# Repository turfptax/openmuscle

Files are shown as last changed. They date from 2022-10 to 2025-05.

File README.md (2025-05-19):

# 🧠 OpenMuscle (Legacy Repository)

> 📢 **NOTE:** This repository is no longer actively maintained.  
> All current work has moved to the new [**Open-Muscle GitHub Organization**](https://github.com/Open-Muscle).  
> Please see the new [OpenMuscle Hub](https://github.com/Open-Muscle/OpenMuscle-Hub) for the latest devices, firmware, and documentation.

---

## ⚡ Quick Links to New Repositories

| Project | Description | Link |
|---|---|---|
| **OpenMuscle Hub** | Central documentation and overview for all OpenMuscle projects | [OpenMuscle-Hub](https://github.com/Open-Muscle/OpenMuscle-Hub) |
| **FlexGrid** | Modular 60-sensor wearable (successor to OM12) | [OpenMuscle-FlexGrid](https://github.com/Open-Muscle/OpenMuscle-FlexGrid) |
| **LASK5** | Labeling device with joystick and buttons | [OpenMuscle-LASK5](https://github.com/Open-Muscle/OpenMuscle-LASK5) |
| **Software** | MicroPython firmware, communication protocols, and ML hooks | [OpenMuscle-Software](https://github.com/Open-Muscle/OpenMuscle-Software) |
| **OM12 Legacy Band** | Historical 12-sensor band hardware | [OpenMuscle-Band](https://github.com/Open-Muscle/OpenMuscle-Band) |

---

## 🧬 About This Repo

This was the **original prototype** of OpenMuscle (OM12 + LASK4), developed to prove out muscle-based finger tracking using off-the-shelf parts and MicroPython.

It remains here for archival purposes and for those referencing:
- Early research and design iterations
- Press and academic mentions (42+ stars)
- Explorations in UDP-based muscle telemetry using hall effect sensors

<div align="center">
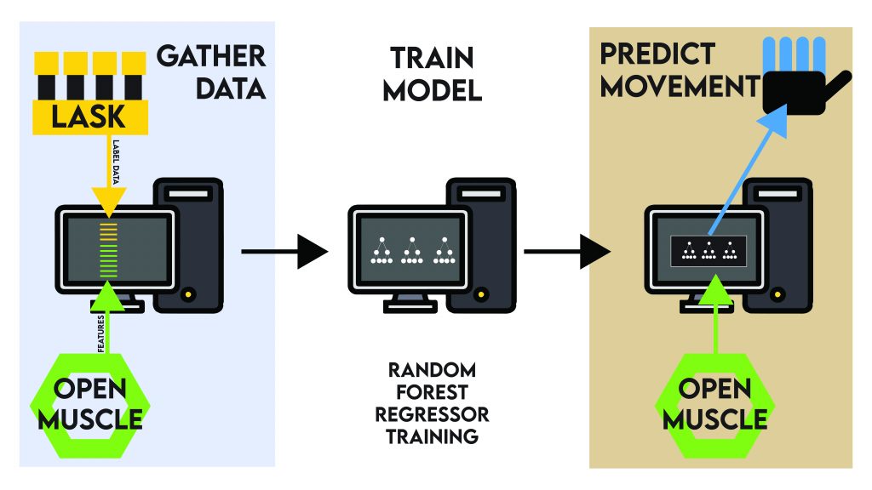
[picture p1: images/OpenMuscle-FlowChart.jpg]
OpenMuscle Flow Chart
    
</div>

---

## 🧪 Prototype Overview

### 🧠 OM12 – OpenMuscle 12 Sensor Band (v5.3.0)

- 12 Hall Effect Sensors (49E)
- 6 Sensor Cells, dual-input
- PCB 5.3.0
- ESP32-S2
- MicroPython
- 1200 s/s via UDP transmission

### ✋ LASK4 (Legacy)

- 4 pistons
- 4 push buttons
- OLED screen
- ESP32-S2 Microcontroller

> The latest version is [LASK5](https://github.com/Open-Muscle/OpenMuscle-LASK5), with joystick and modular controls.

---

## ✅ Legacy Roadmap (Preserved for Context)

- [x] Create an open-source forearm bracelet (OM12)
- [x] Build a hand gesture labeling device (LASK4)
- [x] Create UDP-based data capture tool
- [ ] Build a hosted data training server
- [ ] Raise community awareness
- [ ] Create pre-production versions of both devices

---

## 🧾 License

This repo remains under the MIT License, but newer repositories may use the CERN-OHL-S v2.0 for hardware components. See the respective repos for details.

---

Made with 💡 by [@TURFPTAx](https://github.com/turfptax)  
Project now maintained at [Open-Muscle](https://github.com/Open-Muscle)

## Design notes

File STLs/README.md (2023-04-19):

# STL Files for Open Muscle

## OM12 Foam

Most recent design that reduces cost and time of manufactoring

## OM12 Clevis Pin

Best signal-to-noise ratio design. Used for datasetONE and January23.csv

#### Clevis Pin Sensors
<br />
<div align="center">
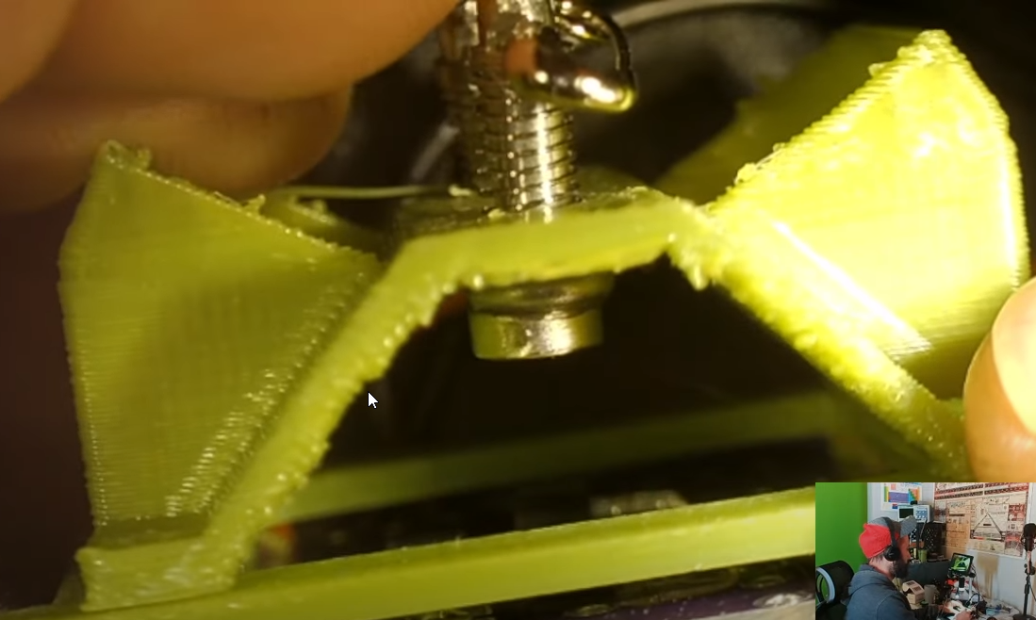
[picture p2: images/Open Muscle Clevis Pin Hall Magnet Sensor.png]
    
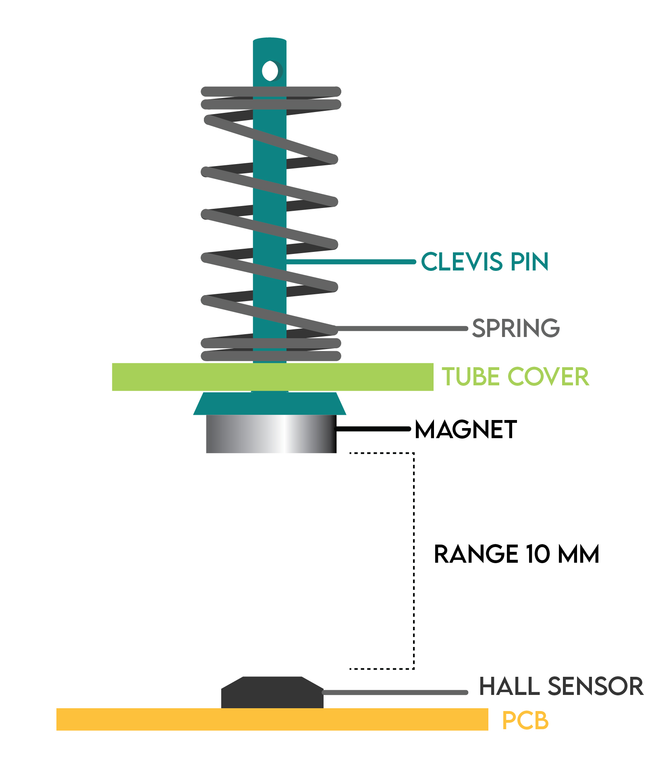
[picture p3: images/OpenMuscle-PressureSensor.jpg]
    
</div>

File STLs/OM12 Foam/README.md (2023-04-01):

# STL Files for Open Muscle

## OM12-BeltHolder
Main PCB bracer and has loops for the elastic band

## OM12-FoamHolder
Sensor side piece that holds the foam/magnet sensors

## OM12-Magnet Tool 6x3
Tool to help glue the magnets onto the rubber sheet.

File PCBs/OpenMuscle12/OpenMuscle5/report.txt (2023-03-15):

Plotted to 'C:\Users\ToryMoghadam\TMO-GMO-FILES\CELL0\OpenMuscle5\OpenMuscle5\OM5-Gerber\OpenMuscle5-F_Cu.gbr'.
Plotted to 'C:\Users\ToryMoghadam\TMO-GMO-FILES\CELL0\OpenMuscle5\OpenMuscle5\OM5-Gerber\OpenMuscle5-B_Cu.gbr'.
Plotted to 'C:\Users\ToryMoghadam\TMO-GMO-FILES\CELL0\OpenMuscle5\OpenMuscle5\OM5-Gerber\OpenMuscle5-F_Paste.gbr'.
Plotted to 'C:\Users\ToryMoghadam\TMO-GMO-FILES\CELL0\OpenMuscle5\OpenMuscle5\OM5-Gerber\OpenMuscle5-B_Paste.gbr'.
Plotted to 'C:\Users\ToryMoghadam\TMO-GMO-FILES\CELL0\OpenMuscle5\OpenMuscle5\OM5-Gerber\OpenMuscle5-F_Silkscreen.gbr'.
Plotted to 'C:\Users\ToryMoghadam\TMO-GMO-FILES\CELL0\OpenMuscle5\OpenMuscle5\OM5-Gerber\OpenMuscle5-B_Silkscreen.gbr'.
Plotted to 'C:\Users\ToryMoghadam\TMO-GMO-FILES\CELL0\OpenMuscle5\OpenMuscle5\OM5-Gerber\OpenMuscle5-F_Mask.gbr'.
Plotted to 'C:\Users\ToryMoghadam\TMO-GMO-FILES\CELL0\OpenMuscle5\OpenMuscle5\OM5-Gerber\OpenMuscle5-B_Mask.gbr'.
Plotted to 'C:\Users\ToryMoghadam\TMO-GMO-FILES\CELL0\OpenMuscle5\OpenMuscle5\OM5-Gerber\OpenMuscle5-Edge_Cuts.gbr'.
Created Gerber job file 'C:\Users\ToryMoghadam\TMO-GMO-FILES\CELL0\OpenMuscle5\OpenMuscle5\OM5-Gerber\OpenMuscle5-job.gbrjob'.
Plotted to 'C:\Users\ToryMoghadam\TMO-GMO-FILES\CELL0\OpenMuscle5\OpenMuscle5\OM5-Gerber\OpenMuscle5-F_Cu.gbr'.
Plotted to 'C:\Users\ToryMoghadam\TMO-GMO-FILES\CELL0\OpenMuscle5\OpenMuscle5\OM5-Gerber\OpenMuscle5-B_Cu.gbr'.
Plotted to 'C:\Users\ToryMoghadam\TMO-GMO-FILES\CELL0\OpenMuscle5\OpenMuscle5\OM5-Gerber\OpenMuscle5-F_Paste.gbr'.
Plotted to 'C:\Users\ToryMoghadam\TMO-GMO-FILES\CELL0\OpenMuscle5\OpenMuscle5\OM5-Gerber\OpenMuscle5-B_Paste.gbr'.
Plotted to 'C:\Users\ToryMoghadam\TMO-GMO-FILES\CELL0\OpenMuscle5\OpenMuscle5\OM5-Gerber\OpenMuscle5-F_Silkscreen.gbr'.
Plotted to 'C:\Users\ToryMoghadam\TMO-GMO-FILES\CELL0\OpenMuscle5\OpenMuscle5\OM5-Gerber\OpenMuscle5-B_Silkscreen.gbr'.
Plotted to 'C:\Users\ToryMoghadam\TMO-GMO-FILES\CELL0\OpenMuscle5\OpenMuscle5\OM5-Gerber\OpenMuscle5-F_Mask.gbr'.
Plotted to 'C:\Users\ToryMoghadam\TMO-GMO-FILES\CELL0\OpenMuscle5\OpenMuscle5\OM5-Gerber\OpenMuscle5-B_Mask.gbr'.
Plotted to 'C:\Users\ToryMoghadam\TMO-GMO-FILES\CELL0\OpenMuscle5\OpenMuscle5\OM5-Gerber\OpenMuscle5-Edge_Cuts.gbr'.
Created Gerber job file 'C:\Users\ToryMoghadam\TMO-GMO-FILES\CELL0\OpenMuscle5\OpenMuscle5\OM5-Gerber\OpenMuscle5-job.gbrjob'.
Info: Done.
Info: Done.

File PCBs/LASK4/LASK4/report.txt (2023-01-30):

Plotted to 'C:\Users\ToryMoghadam\OneDrive - Rural Health Development\Documents\GitHub\openmuscle\PCBs\LASK4\LASK4\LASK4-GERBER\LASK4-F_Cu.gbr'.
Plotted to 'C:\Users\ToryMoghadam\OneDrive - Rural Health Development\Documents\GitHub\openmuscle\PCBs\LASK4\LASK4\LASK4-GERBER\LASK4-B_Cu.gbr'.
Plotted to 'C:\Users\ToryMoghadam\OneDrive - Rural Health Development\Documents\GitHub\openmuscle\PCBs\LASK4\LASK4\LASK4-GERBER\LASK4-F_Paste.gbr'.
Plotted to 'C:\Users\ToryMoghadam\OneDrive - Rural Health Development\Documents\GitHub\openmuscle\PCBs\LASK4\LASK4\LASK4-GERBER\LASK4-B_Paste.gbr'.
Plotted to 'C:\Users\ToryMoghadam\OneDrive - Rural Health Development\Documents\GitHub\openmuscle\PCBs\LASK4\LASK4\LASK4-GERBER\LASK4-F_Silkscreen.gbr'.
Plotted to 'C:\Users\ToryMoghadam\OneDrive - Rural Health Development\Documents\GitHub\openmuscle\PCBs\LASK4\LASK4\LASK4-GERBER\LASK4-B_Silkscreen.gbr'.
Plotted to 'C:\Users\ToryMoghadam\OneDrive - Rural Health Development\Documents\GitHub\openmuscle\PCBs\LASK4\LASK4\LASK4-GERBER\LASK4-F_Mask.gbr'.
Plotted to 'C:\Users\ToryMoghadam\OneDrive - Rural Health Development\Documents\GitHub\openmuscle\PCBs\LASK4\LASK4\LASK4-GERBER\LASK4-B_Mask.gbr'.
Plotted to 'C:\Users\ToryMoghadam\OneDrive - Rural Health Development\Documents\GitHub\openmuscle\PCBs\LASK4\LASK4\LASK4-GERBER\LASK4-Edge_Cuts.gbr'.
Created Gerber job file 'C:\Users\ToryMoghadam\OneDrive - Rural Health Development\Documents\GitHub\openmuscle\PCBs\LASK4\LASK4\LASK4-GERBER\LASK4-job.gbrjob'.
Info: Done.

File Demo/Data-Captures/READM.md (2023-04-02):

# Capture Set With 3 separate files
capture_08.txt
capture_09.txt
capture_10.txt

# Best Capture January23
Also named datasetONE.txt in some cases. 

# Filter Data & Convert to CSV
sensor_data_filter.py is used to match LASK and Open Muscle Packets.

It also converts the file into CSV format for machine learning.

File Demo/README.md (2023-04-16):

## Demo Files

See Wiki

# Use the Demo folder for training your own model

# Quick Setup

1. Run train_model_time.py
2. Run demo_live_time_predictions.py
3. While the demo is running run virtual_sensor_transmitter.py to send virtual data packets to the demo

# Dependencies

scikit-learn
pandas
pygame

```
pip install scikit-learn pandas pygame
```

## train_model.py

Train-Model.py is setup to use the 'Trained-Demo-Model.pkl' pickle file as an export.

The input CSV file is 'Data-Captures/capture_11.csv'

When you run the program it will feed in the data from the csv file and train it with the 12 features and the 4 labels. These labels are also referred to as tokens, but they are supplying the model with the desired outputs from the system.

For the demo file it takes ~2 minutes to train the model.

It will also export the 20% of the test data with the predictions to a CSV file.

The model is stored inside of the pickle file to be used to make live predictions.

# Convert data to CSV Format
If you do not have the data in CSV format from open muscle you will need to use the 'Data-Captures' folder to take the raw text file json and convert it.

## sensor_data_filter.py
The convert training data program takes the raw text json file from the recorded session and pairs the LASK data with the Open Muscle data.

Since UDP packets come in one at a time, we will have to pair them by timestamps and throw out data that does not have a pair.

# Predicting Live Data

Live data can use the LASK system to show its accuracy or it can be used without the LASK system.

Since the movement that we trained is specific to the motion that the LASK mechanical design provides it is suggested to use the LASK system while it is turned off.

## virtual_lask_zero_values.py
Since the algorithm that filters the packets in the training phase, the same algorithm will have to be applied to the real-time data. For now we are suggesting to use the 'virtual_lask_zero_values.py' to send 'dummy' lask data if you plan on not using the LASK system during real-time predictions.

## demo_live_predictions.py

If you have trained your model and want to see live predictions use the live demo predictions program.

This will
1. Load the model
2. Great a GUI
3. Listen for Open Muscle and LASK packets
4. Filter the packets
5. Send data to the Model
6. Draw model predictions over actual or dummy data

## Using a Virtual Open Muscle and LASK

If you just want to see the model work in real-time we have supplied 2 short training files 11 and 12.

The model, by default, is trained on capture_11. 

### virtual_sensor_transmitter.py
You can use the 'virtual_sensor_transmitter.py' program to send the packets over UDP to yourself.
It takes capture_12, by default, and sends the raw packets as a virutal device(s)

This allows you to run both the mimic program and the Live Demo Predictions program at the same time to see the predictions from the precaptured dataset.

# Training Different Files
If you want to use one of the other two Data-Capture files instead of capture 9, you will just have to modify the 'Train-Model.py' code and rename the CSV file;
data = pd.read_csv('Data-Captures/capture_9.csv')
I have already used the 'filter-training-data-convert-CSV.py' on the three training files but you can also convert them into CSV by changing the code in the conversion file to the other txt file.

# Results for Training on capture_11.csv
- Mean Squared Error: 7689.885189928801
- Mean Absolute Error: 29.919568537049315

# Results for Training on January23.csv
- Mean Squared Error: 6131.50072204039
- Mean Absolute Error: 23.225226598136324
- Training session video was also recorded here: [https://www.youtube.com/watch?v=BRkbyyItcVQ](https://youtu.be/BRkbyyItcVQ))

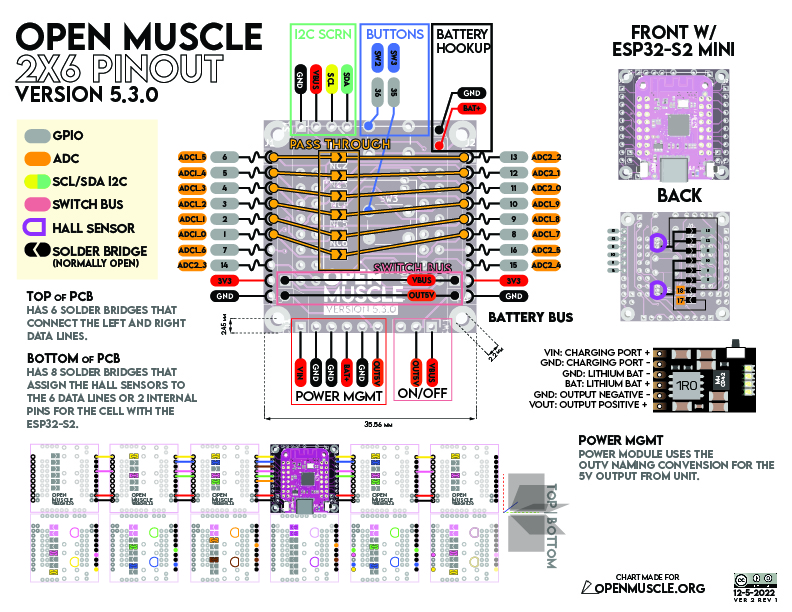
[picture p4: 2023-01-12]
images/OpenMuscleV530Pinout-01.jpg

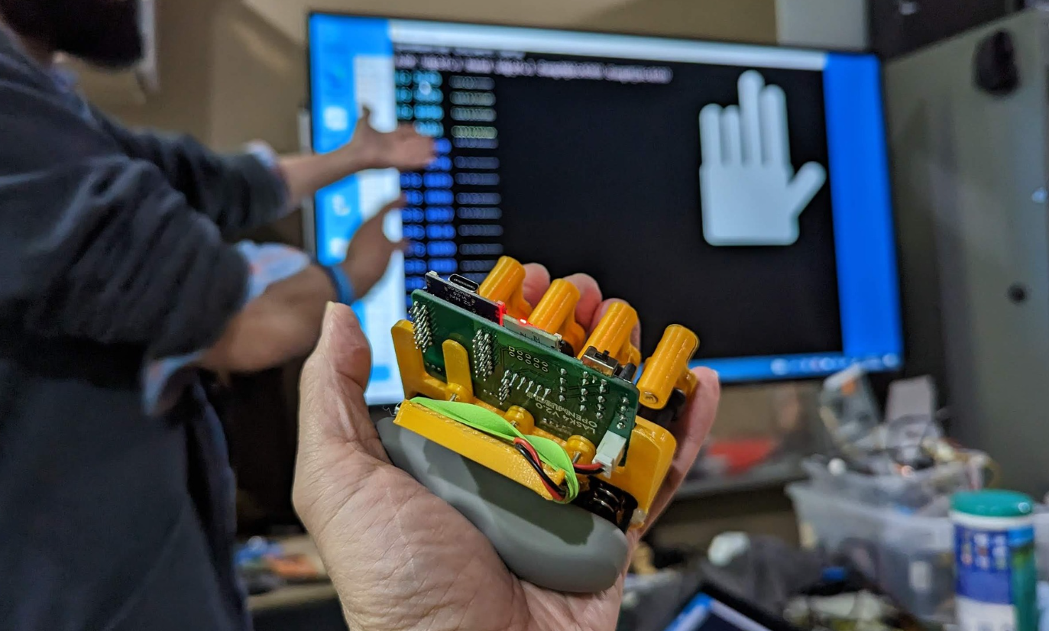
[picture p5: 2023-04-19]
images/LASK-LivePredictions.png

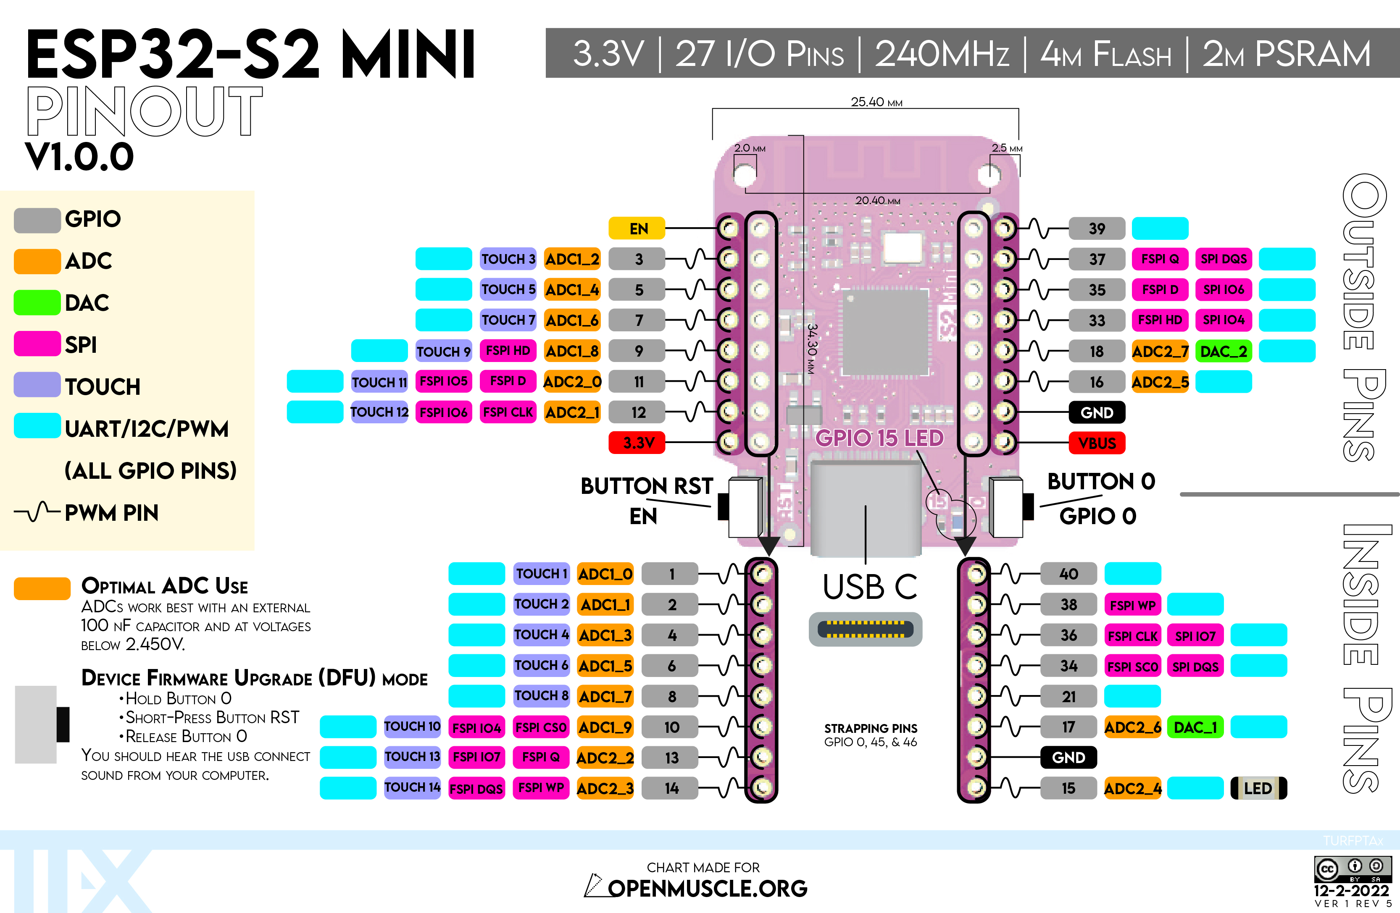
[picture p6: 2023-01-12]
images/ESP32_S2_mini_V2-R6-01.jpg

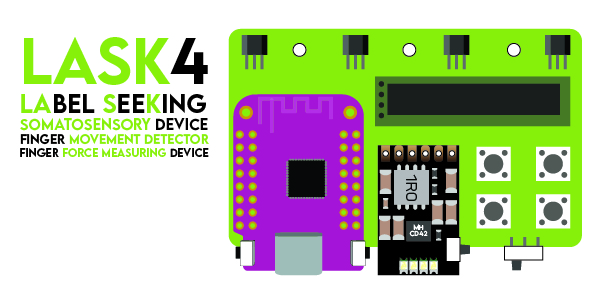
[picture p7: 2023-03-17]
images/LASK4v2-01.jpg

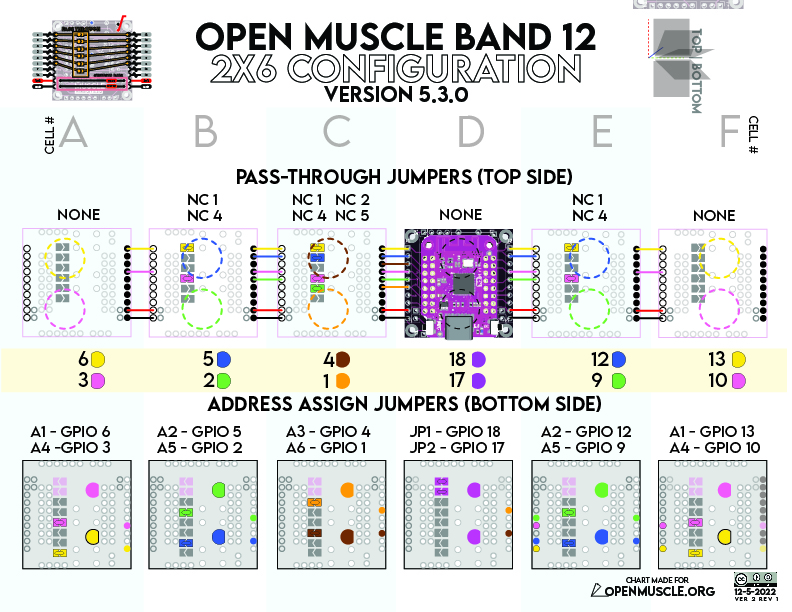
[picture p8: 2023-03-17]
images/OM-Band12 5-3-0-02.jpg

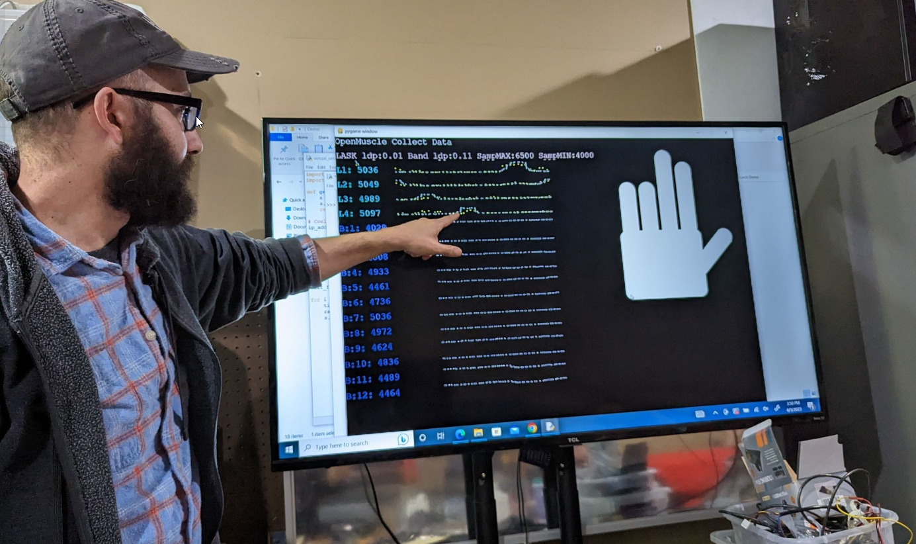
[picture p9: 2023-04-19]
images/OM-LivePredictions.png

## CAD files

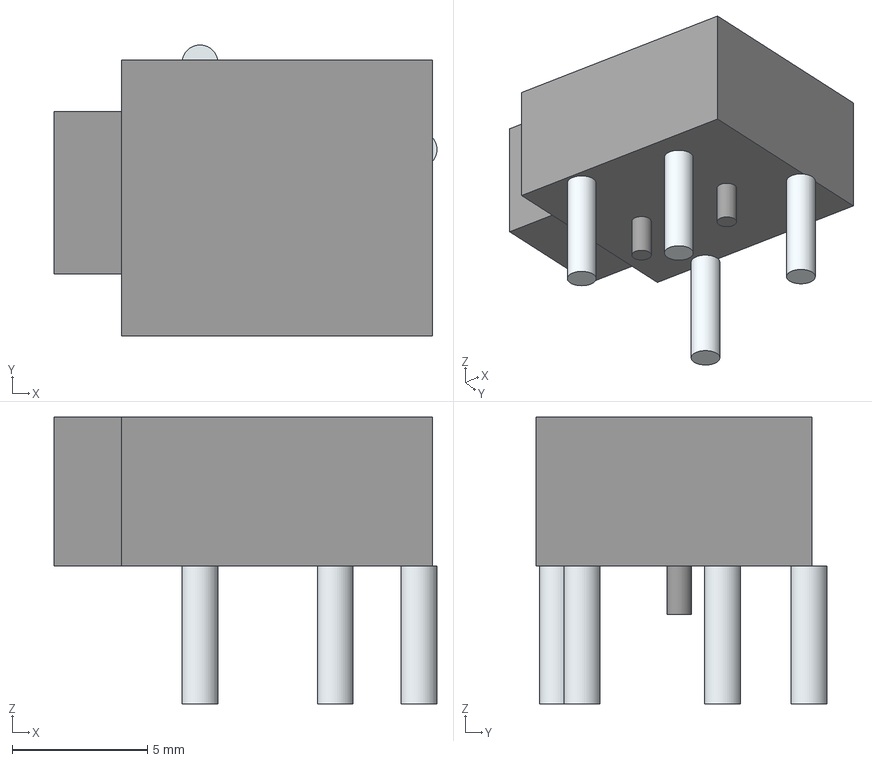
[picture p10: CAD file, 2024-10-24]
PCBs/OMDevKitBracelet/LIB_35RAPC5CHWNSN (1)/35RAPC5CHWNSN/3D/35RAPC5CHWNSN.stp
14.2 x 10.8 x 10.6 mm
Lugs
Leads

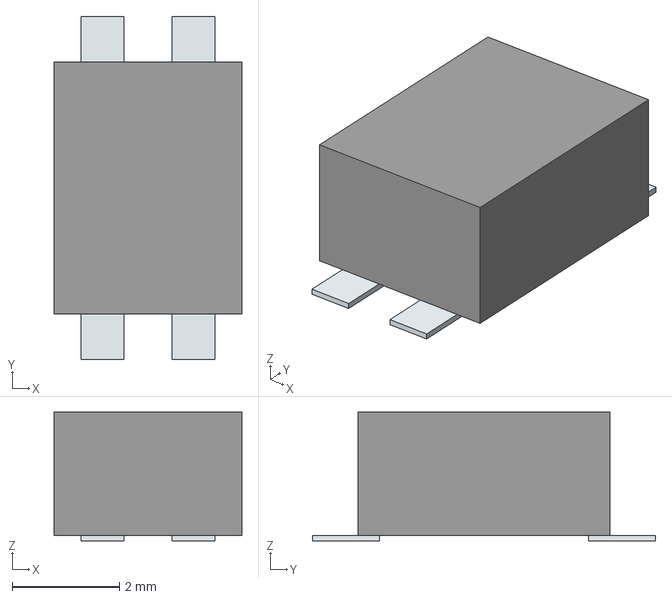
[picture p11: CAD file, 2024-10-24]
PCBs/OMDevKitBracelet/LIB_EVQ-P2P02M/EVQ-P2P02M/3D/EVQ-P2P02M.stp
3.50 x 6.40 x 2.40 mm
Pins

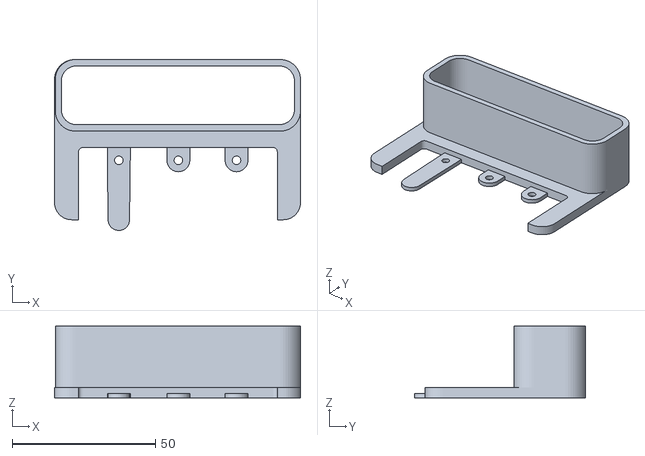
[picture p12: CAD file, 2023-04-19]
STLs/LASK4/LASK4-BASEv2.stl
86.0 x 59.7 x 25.0

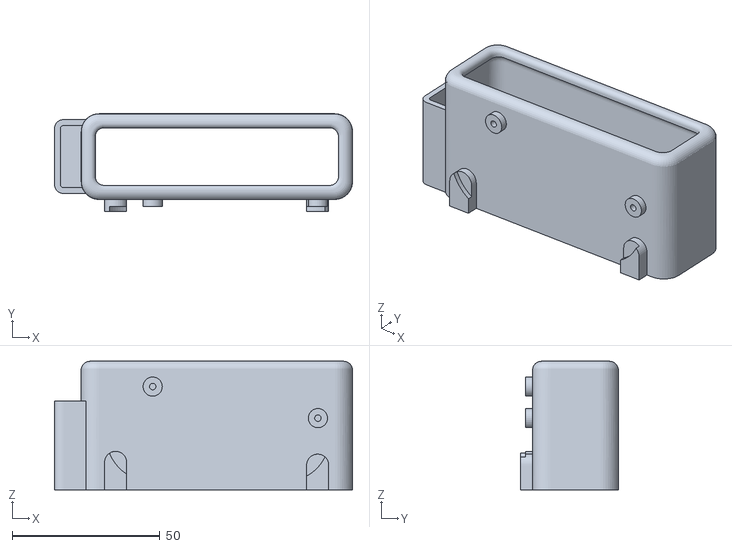
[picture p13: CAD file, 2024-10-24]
STLs/LASK5/LASK5-BatteryHolder.stl
100.8 x 33.0 x 43.5

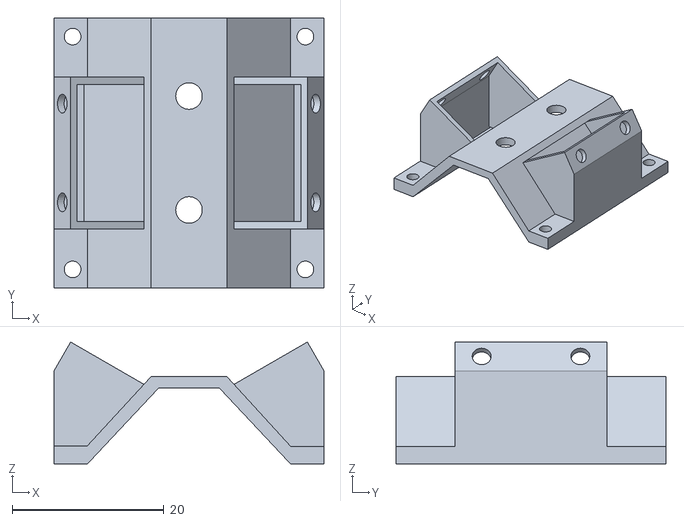
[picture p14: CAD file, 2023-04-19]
STLs/OM12 Clevis Pin/OpenMuscle5-3-0 ClevisHolder.stl
35.6 x 35.6 x 16.1

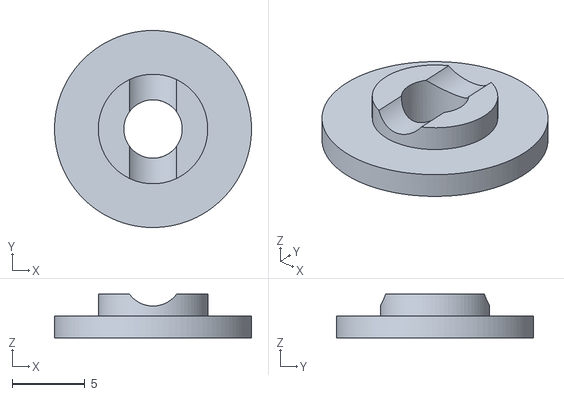
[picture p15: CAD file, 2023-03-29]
STLs/OM12 Foam/ClevisFeet.stl
13.5 x 13.5 x 3.00

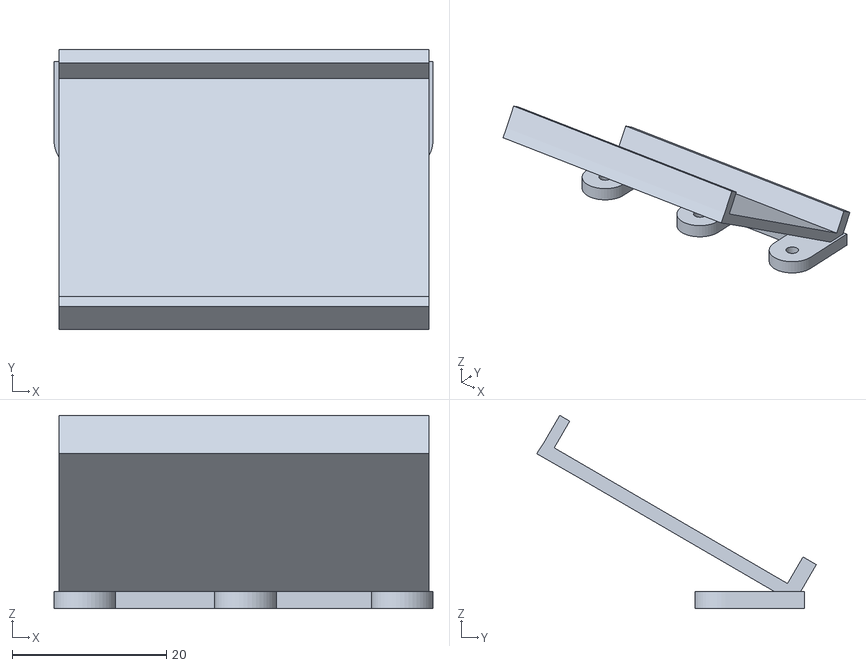
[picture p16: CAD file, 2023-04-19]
STLs/LASK4/LASK4-BatteryHolder.stl
49.2 x 36.3 x 25.1

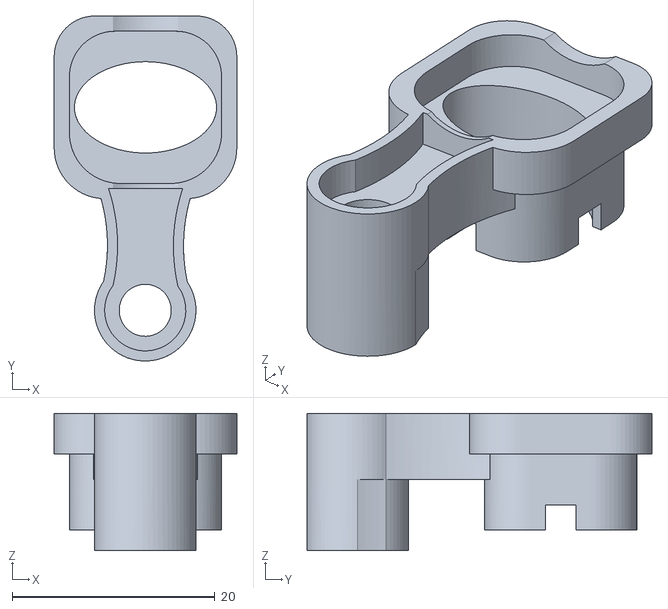
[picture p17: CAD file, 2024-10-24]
STLs/LASK5/uLabel-Depressor-v31.stl
18.0 x 34.0 x 13.5

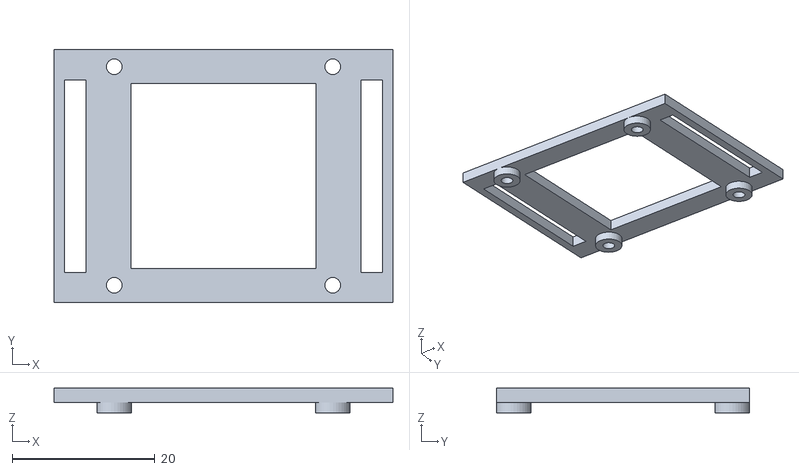
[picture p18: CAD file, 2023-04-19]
STLs/OM12 Clevis Pin/OpenMuscle5-3-0 PCBPlate.stl
47.6 x 35.6 x 3.50

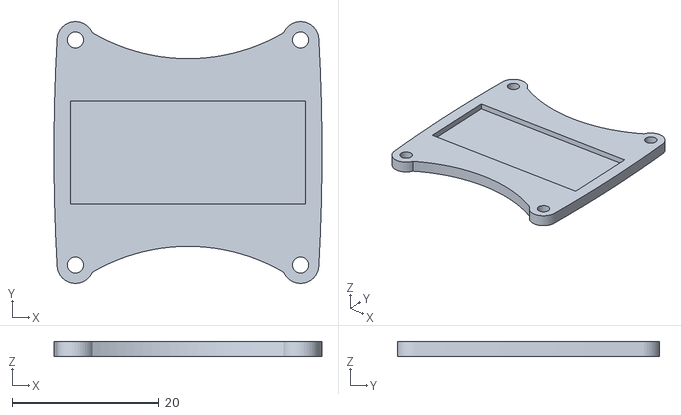
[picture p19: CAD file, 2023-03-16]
STLs/OM12 Foam/OM12-FoamHolder.stl
36.5 x 35.7 x 2.00

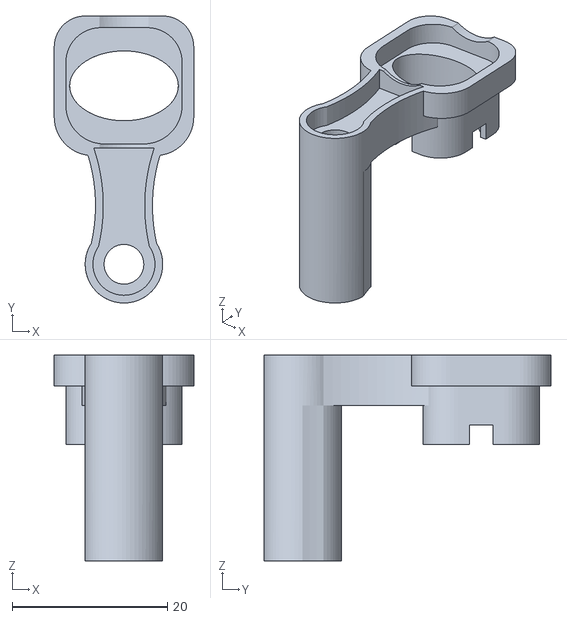
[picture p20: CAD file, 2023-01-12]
STLs/LASK4/LASK4-MagnetDepressors.stl
18.0 x 37.0 x 26.5

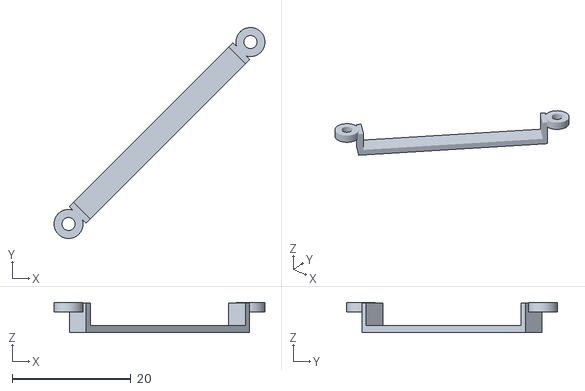
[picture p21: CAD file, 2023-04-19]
STLs/OM12 Clevis Pin/OpenMuscle5-3-0 BatteryHolder.stl
35.6 x 35.6 x 5.07

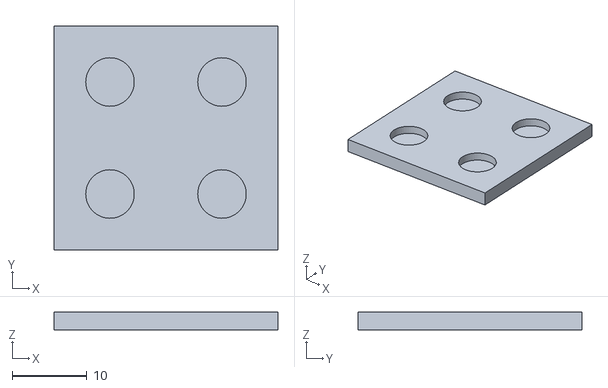
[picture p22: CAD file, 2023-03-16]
STLs/OM12 Foam/OM12-Magnet Tool 6x3.stl
30.0 x 30.0 x 2.40

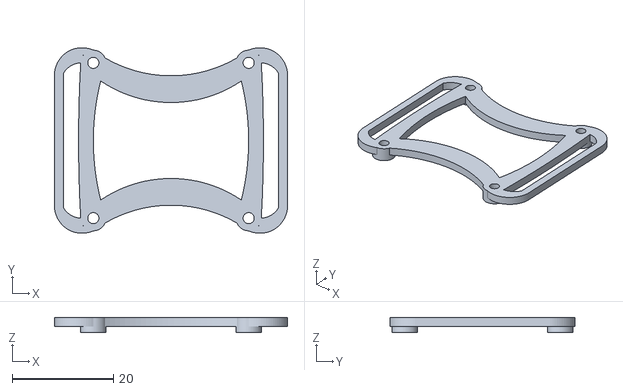
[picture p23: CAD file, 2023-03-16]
STLs/OM12 Foam/OM12-BeltHolder.stl
46.0 x 36.6 x 3.00

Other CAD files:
PCBs/OMDevKitBracelet/LIB_35RAPC5CHWNSN (1)/35RAPC5CHWNSN/Allegro/35rapc5chwnsn.psm
PCBs/OMDevKitBracelet/LIB_35RAPC5CHWNSN (1)/35RAPC5CHWNSN/DEHDL/35rapc5chwnsn/chips/chips.prt
PCBs/OMDevKitBracelet/LIB_EVQ-P2P02M/EVQ-P2P02M/Allegro/evqp2p02m.psm
PCBs/OMDevKitBracelet/LIB_EVQ-P2P02M/EVQ-P2P02M/DEHDL/evq_p2p02m/chips/chips.prt

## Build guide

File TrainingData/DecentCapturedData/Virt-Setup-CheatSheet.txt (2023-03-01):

# Need to use virtual environment to run the code
# Note created 3-1-2023 - TURFPTAx
# using book: HANDS-ON MACHINE LEARNING WITH SCIKIT-LEARN, KERAS & TENSORFLOW
# O'REILLY 2nd Edition
# Instructions on page 43 and 44

# Virtual environment located on my F drive
F:\TTXONE\OneDrive - TURFPTAx\Documents\GitHub\openmuscle\Machine Learning

# Instructions to activate virtual environment after setup:

cd $ML_PATH
source my_env/bin/activate # on Linux or macOS
.\my_env\Scripts\activate  # on Windows

- name of envelope or my_env: om_env

# On my windows machine use: .\om_env\Scripts\activate

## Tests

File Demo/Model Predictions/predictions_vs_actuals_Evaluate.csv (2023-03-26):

Actual LASK1 | Actual LASK2 | Actual LASK3 | Actual LASK4 | LASK_time | Predicted LASK1 | Predicted LASK2 | Predicted LASK3 | Predicted LASK4
5000 | 4309 | 5024 | 5197 | 76.86404538154602 | 5023.442452380952 | 4277.887285714286 | 5033.495261904762 | 5207.021753968254
5044 | 5076 | 4953 | 5229 | 259.8539180755615 | 5042.946075396824 | 5069.565880952381 | 4970.88848015873 | 5228.907753968251
5072 | 5073 | 4996 | 5232 | 292.2065374851227 | 5042.406206349206 | 5071.740646825398 | 4987.054456349206 | 5219.679507936507
5065 | 5045 | 5028 | 4412 | 129.02851915359497 | 5042.380073953824 | 5080.280471861472 | 5021.547227994229 | 4400.700990981242
5052 | 5068 | 4977 | 5220 | 262.5086236000061 | 5045.322976190477 | 5069.204305555556 | 4987.370065934066 | 5210.2945714285715
4993 | 4289 | 5053 | 5209 | 157.86443090438843 | 5004.948796037296 | 4338.619666666667 | 5021.388115384615 | 5251.989047619048
5037 | 4961 | 4988 | 5248 | 162.88646173477173 | 5020.4346731601745 | 4654.077989177489 | 5000.193756854256 | 5217.357468253968
5012 | 5077 | 4977 | 5225 | 265.6846058368683 | 5011.851047619048 | 5053.879761904762 | 4985.555714285714 | 5213.900690476191
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

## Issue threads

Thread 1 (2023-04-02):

Lack of Filters and callibration

turfptax, 2023-04-02:
Need to work on the calibration of the sensors.

High Pass Filter
Smoothing Techniques
Others

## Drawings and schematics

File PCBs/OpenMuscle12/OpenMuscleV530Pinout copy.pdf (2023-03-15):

# OPEN MUSCLE

# VERSION 5.3.0

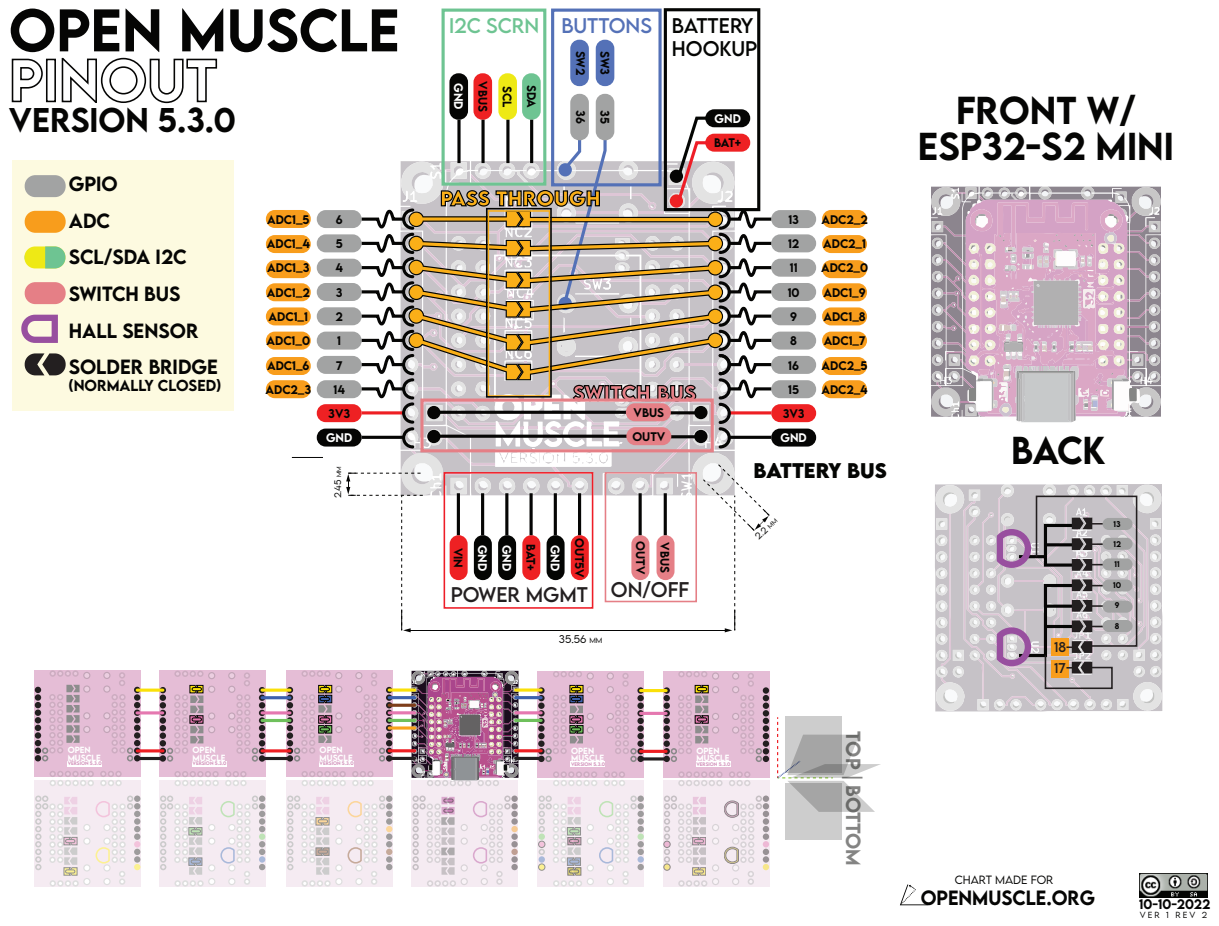
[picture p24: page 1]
OPEN MUSCLE VERSION 5.3.0; 10-10-2022 VER 1 REV 2; GPIO; ADC; SCL/SDA I2C; SWiTCH BUS; HALL SENSOR; SOLDER BRiDGE (NORMALLY CLOSED); FRONT W/ ESP32-S2 MiNi; TURFPTAX; BACK; GND; ADC2_2; ADC2_1; ADC2_0; ADC1_9; ADC1_8; ADC1_7; ADC2_5; ADC2_4; ADC1_5; ADC1_4; ADC1_3; ADC1_2; ADC1_1; ADC1_0; ADC1_6; ADC2_3; VBUS; SCL; SDA; OUT5V; VIN; BAT+; POWER MGMT; PASS THROUGH; BATTERY BUS; BATTERY HOOKUP; i2C SCRN BUTTONS; ON/OFF; TOP | BOTTOM

SWITCH BUS
OUTV OUTV VBUS

CHART MADE FOR
OPENMUSCLE.ORG

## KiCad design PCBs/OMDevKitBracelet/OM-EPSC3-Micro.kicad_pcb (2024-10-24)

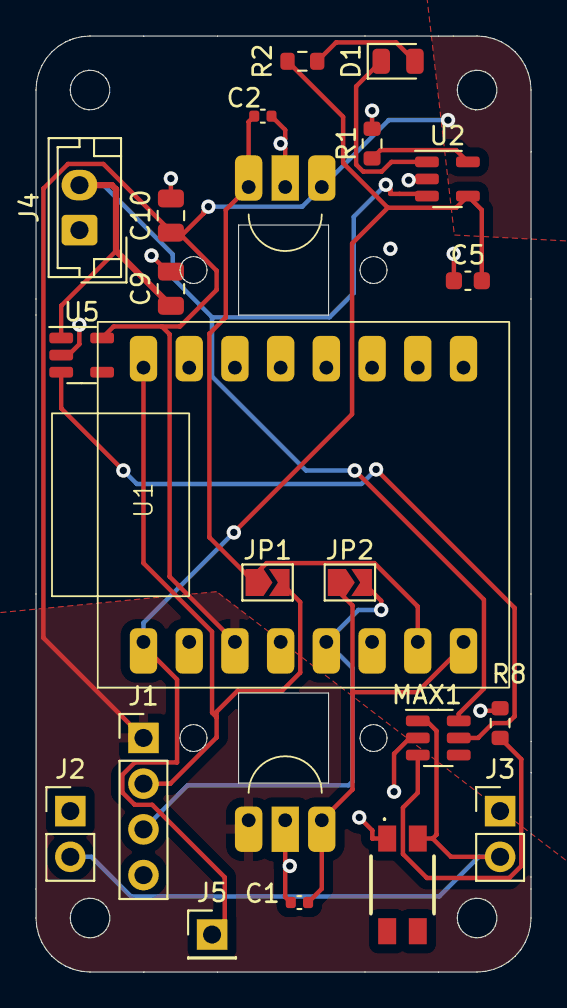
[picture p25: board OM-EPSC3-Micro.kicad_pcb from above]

Board: 2 copper layers, 27.5 x 52.0 mm, 23 parts (0 on the bottom side), 14 nets.

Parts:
C1, C2: 100 nF; C_0402_1005Metric
C5: 2.2 uF; C_0603_1608Metric
C9, C10: 4.7uF; C_0805_2012Metric
D1: LED GREEN; LED_0805_2012Metric
H0, H1: A1369xUA-10; Hall49E
J1: Conn_01x04_Pin; PinHeader_1x04_P2.54mm_Vertical
J2, J3: Conn_01x02_Pin; PinHeader_1x02_P2.54mm_Vertical
J4: JST_02; JST_EH_B2B-EH-A_1x02_P2.50mm_Vertical
J5: Conn_01x01_Pin; PinHeader_1x01_P2.54mm_Vertical
JP1, JP2: SolderJumper_2_Open; SolderJumper-2_P1.3mm_Open_TrianglePad1.0x1.5mm
MAX1: SOT-23-6
R1: 2.7k; R_0603_1608Metric
R2: 150; R_0603_1608Metric
R8: 1K; R_0603_1608Metric
SW2: SW_Push; EVQP2P02M
U1: ESP32-C3-Super Mini
U2: LTC4054ES5-4.2; TSOT-23-5
U5: TPS7A03; SOT-23-5

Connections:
+3V3: C10.1, H0.1 (VCC), H1.1 (VCC), J1.1, U1.102 (3V3), U5.5 (OUT)
+3V8: C9.1, J4.1, MAX1.6 (Vcc), U2.3 (BAT), U5.1 (IN)
+5V: C5.2, J5.1, R2.1, U1.100 (5V), U2.4 (V_{CC})
ADC2: J1.3, JP2.2 (B), U1.3 (GPIO3)
ADC3: J1.2, JP1.2 (B), U1.5 (GPIO5)
GND: C1.1, C2.1, C5.1, C9.2, C10.2, H0.2 (GND), H1.2 (GND), J1.4, J2.1, J3.1, J4.2, MAX1.2 (GND), R1.2, R8.2, SW2.1, U1.101 (GND), U2.2 (GND), U5.2 (GND)
LDO_EN: MAX1.5 (OUT), U5.3 (EN)
unnamed: D1.2 (A), R2.2
unnamed: D1.1 (K), U2.1 (~CHRG)
unnamed: MAX1.3 (CLEAR), R8.1
unnamed: R1.1, U2.5 (PROG)
RMT-BTN: J2.2, J3.2, MAX1.1 (In), SW2.2
hall_0: C1.2, H0.3 (VOUT), JP2.1 (A), U1.0 (GPIO0)
hall_1: C2.2, H1.3 (VOUT), JP1.1 (A), U1.1 (GPIO1)

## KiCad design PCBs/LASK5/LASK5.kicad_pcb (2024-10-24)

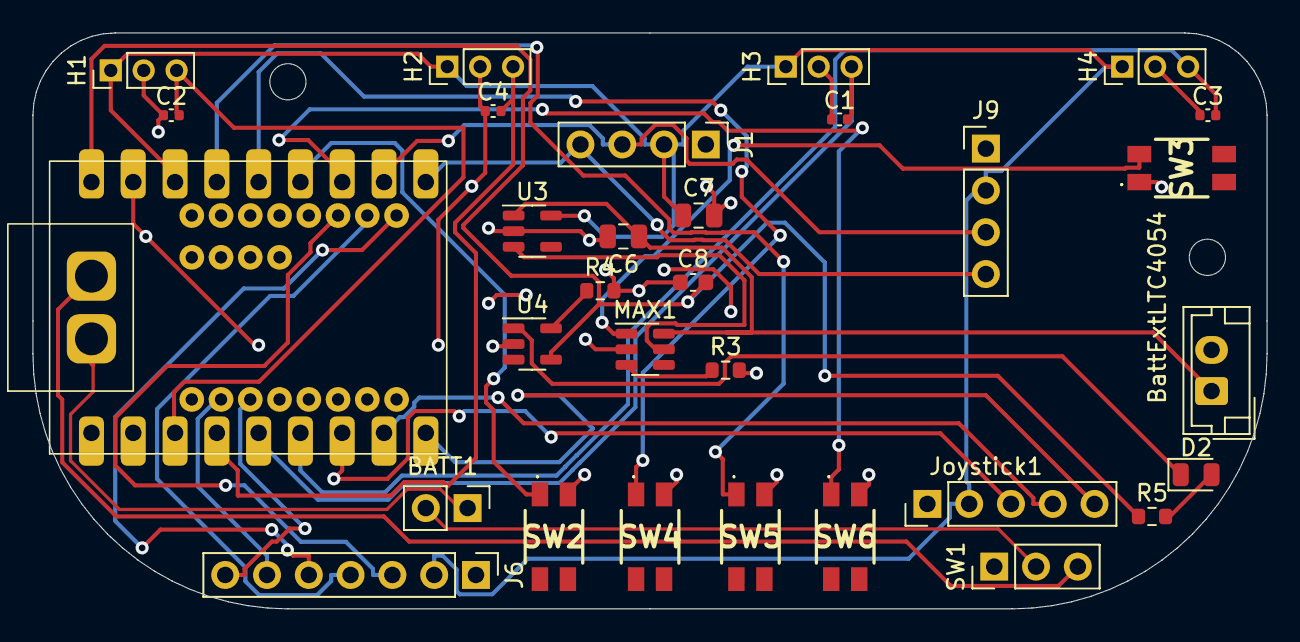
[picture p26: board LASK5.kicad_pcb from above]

Board: 2 copper layers, 75.0 x 35.0 mm, 33 parts (0 on the bottom side), 31 nets.

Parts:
BATT1: Conn_01x02_Pin; PinHeader_1x02_P2.54mm_Vertical
BattExtLTC4054: JST_02; JST_EH_B2B-EH-A_1x02_P2.50mm_Vertical
C1, C2, C3, C4: 100 nF; C_0402_1005Metric
C6, C7: 4.7uF; C_0805_2012Metric
C8: 2.2 uF; C_0603_1608Metric
D2: LED GREEN; LED_0805_2012Metric
H1, H2, H3, H4: A1369xUA-10; PinHeader_1x03_P2.00mm_Vertical
H7, H8: MountingHole; MountingHole_2.2mm_M2
J1, J9: Conn_01x04; PinHeader_1x04_P2.54mm_Vertical
J6: Conn_01x07_Pin; PinHeader_1x07_P2.54mm_Vertical
Joystick1: Conn_01x05_Pin; PinHeader_1x05_P2.54mm_Vertical
MAX1: SOT-23-6
R3: 1K; R_0603_1608Metric
R4: 2.7k; R_0603_1608Metric
R5: 150; R_0603_1608Metric
SW1: SW_SPDT; PinHeader_1x03_P2.54mm_Vertical
SW2, SW3, SW4, SW5, SW6: SW_Push; EVQP2P02M
U1: ESP32-S3-Super Mini
U3: TPS7A03; SOT-23-5
U4: LTC4054ES5-4.2; TSOT-23-5

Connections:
+3V3: C7.1, H1.1 (VCC), H2.1 (VCC), H3.1 (VCC), H4.1 (VCC), J1.2, J6.2, J9.2, Joystick1.2, U1.103 (3V3), U3.5 (OUT)
+3V8: BattExtLTC4054.1, C6.1, MAX1.6 (Vcc), U3.1 (IN)
+5V: C8.2, R5.1, U1.105 (5V), U4.4 (V_{CC})
BPACK+: BATT1.2, SW1.2 (B)
BPACK-: BATT1.1, U1.384 (BAT-)
BPACKSW+: SW1.3 (C), U1.385 (BAT+)
GND: BattExtLTC4054.2, C1.1, C2.1, C3.1, C4.1, C6.2, C7.2, C8.1, H1.2 (GND), H2.2 (GND), H3.2 (GND), H4.2 (GND), J1.1, J6.1, J9.1, Joystick1.1, MAX1.2 (GND), R3.2, R4.2, SW2.2, SW3.1, SW4.2, SW5.2, SW6.2, U1.100 (GND), U3.2 (GND), U4.2 (GND)
GP14: J6.5, U1.14
GP15: J6.4, U1.15
GP16: J6.3, U1.16
GP46: J6.7, U1.46
GP47: J6.6, U1.47
JSW: Joystick1.5, U1.7 (GP7)
JX: Joystick1.3, U1.5 (GP5)
JY: Joystick1.4, U1.6 (GP6)
LDO_EN: MAX1.5 (OUT), U3.3 (EN)
unnamed: D2.2 (A), R5.2
unnamed: D2.1 (K), U4.1 (~CHRG)
unnamed: MAX1.3 (CLEAR), R3.1
unnamed: R4.1, U4.5 (PROG)
RMT-BTN: MAX1.1 (In), SW3.2
SCL: J1.3, J9.3, U1.9 (GP9)
SDA: J1.4, J9.4, U1.8 (GP8)
b_left: SW4.1, U1.12 (GP12)
b_right: SW5.1, U1.13 (GP13)
b_select: SW6.1, U1.10 (GP10)
b_start: SW2.1, U1.11 (GP11)
hall_0: C2.2, H1.3 (VOUT), U1.1 (GP1)
hall_1: C4.2, H2.3 (VOUT), U1.2 (GP2)
hall_2: C1.2, H3.3 (VOUT), U1.3 (GP3)
hall_3: C3.2, H4.3 (VOUT), U1.4 (GP4)

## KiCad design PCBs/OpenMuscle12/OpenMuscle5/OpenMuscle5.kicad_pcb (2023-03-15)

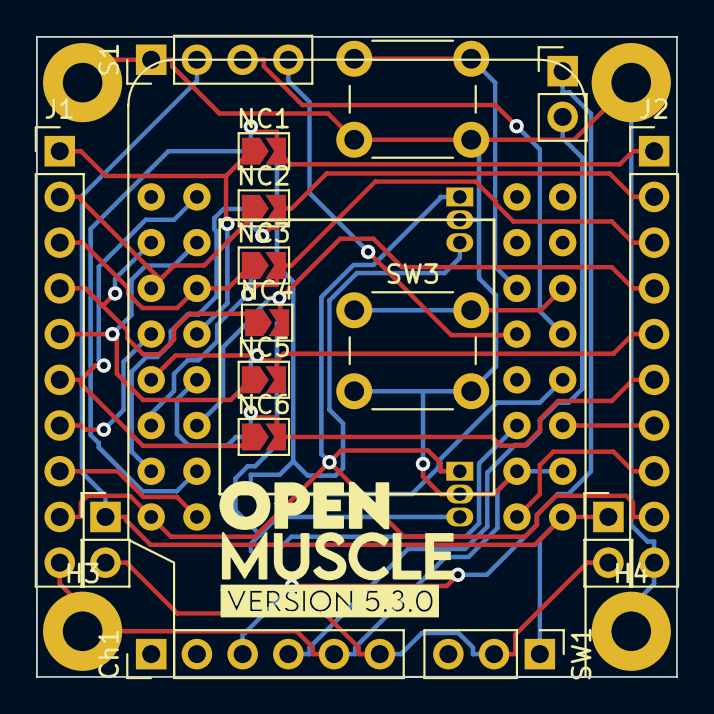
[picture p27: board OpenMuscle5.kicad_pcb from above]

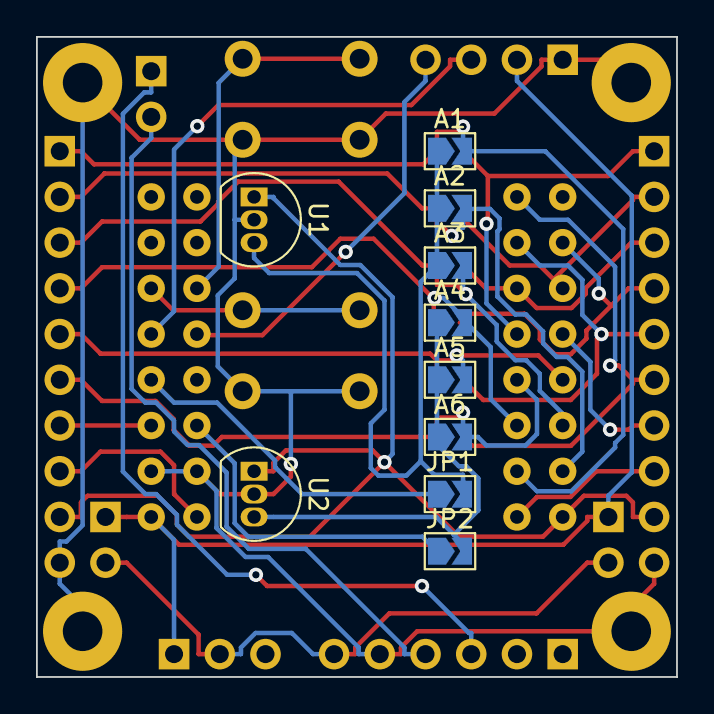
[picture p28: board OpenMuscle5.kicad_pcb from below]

Board: 2 copper layers, 35.6 x 35.6 mm, 31 parts (10 on the bottom side), 30 nets.

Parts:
A1, A2, A3, A4, A5, A6: SolderJumper_2_Open; SolderJumper-2_P1.3mm_Open_TrianglePad1.0x1.5mm
BT1: Conn_01x02_Male; PinHeader_1x02_P2.54mm_Vertical
Ch1: 3.7_Charge_MH_CD42; PinHeader_1x06_P2.54mm_Vertical
E1: ESP32-S2-Mini; ESP32-S2-mini
Five1, Five2: Conn_01x02_Male; PinHeader_1x02_P2.54mm_Vertical
H1, H2, H3, H4: MountingHole_Pad; MountingHole_2.2mm_M2_Pad
J1, J2: Head1x10-OMv5; PinHeader_1x10_P2.54mm_Vertical
JP1, JP2: SolderJumper_2_Open; SolderJumper-2_P1.3mm_Open_TrianglePad1.0x1.5mm
NC1, NC2, NC3, NC4, NC5, NC6: SolderJumper_2_Open; SolderJumper-2_P1.3mm_Open_TrianglePad1.0x1.5mm
S1: SSD1306; PinHeader_1x04_P2.54mm_Vertical
SW1: SW_SPST; PinHeader_1x03_P2.54mm_Vertical
SW2, SW3: SW_Push; SW_PUSH_6mm
U1, U2: DRV5033AJxLPG; TO-92_Inline

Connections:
unnamed: A1.1 (A), A2.1 (A), A3.1 (A), JP1.2 (B), U1.3 (OUT)
unnamed: A1.2 (B), E1.13 (ADC2_2), J2.1 (ACD0), NC1.2 (B)
unnamed: A2.2 (B), E1.12 (ADC2_1), J2.2 (ADC1), NC2.2 (B)
unnamed: A3.2 (B), E1.11 (ADC2_0), J2.3, NC3.2 (B)
unnamed: A4.1 (A), A5.1 (A), A6.1 (A), JP2.2 (B), U2.3 (OUT)
unnamed: A4.2 (B), E1.10 (ADC1_9), J2.4, NC4.2 (B)
unnamed: A5.2 (B), E1.9 (ADC1_8), J2.5, NC5.2 (B)
unnamed: A6.2 (B), E1.8 (ADC1_7), J2.6, NC6.2 (B)
unnamed: BT1.1, Ch1.3 (BAT-GND)
unnamed: BT1.2, Ch1.4 (BAT+)
unnamed: Ch1.6 (OUT-5V), Five1.2, Five2.2, SW1.2 (B)
unnamed: E1.1 (ADC1_0), J1.6, NC6.1 (A)
unnamed: E1.2 (ADC1_1), J1.5, NC5.1 (A)
unnamed: E1.3 (ADC1_2), J1.4, NC4.1 (A)
unnamed: E1.4 (ADC1_3), J1.3, NC3.1 (A)
unnamed: E1.5 (ADC1_4), J1.2 (ADC1), NC2.1 (A)
unnamed: E1.6 (ADC1_5), J1.1 (ACD0), NC1.1 (A)
unnamed: E1.7 (ADC1_6), J1.7
unnamed: E1.14 (ADC2_3), J1.8
unnamed: E1.15 (ADC2_4), J2.8
unnamed: E1.16 (ADC2_5), J2.7
unnamed: E1.17 (ADC2_6), JP2.1 (A)
unnamed: E1.18 (ADC2_7), JP1.1 (A)
unnamed: E1.33 (FSPI_HD_io4), S1.3 (SCL)
unnamed: E1.34 (FSPI_SCO_dqs), S1.4 (SDA)
unnamed: E1.35 (FSPI_D_io6), SW3.1
unnamed: E1.36 (FSPI_CLK_io7), SW2.1
unnamed: E1.133 (3.3V), J1.9, J2.9, U1.1 (VCC), U2.1 (VCC)
unnamed: E1.150 (VBUS), Five1.1, Five2.1, S1.2 (VCC), SW1.1 (A)
unnamed: Ch1.5 (OUT-GND), E1.129 (GND), E1.130 (GND), H1.1, H2.1, H3.1, H4.1, J1.10, J2.10, S1.1 (GND), SW2.2, SW3.2, U1.2 (GND), U2.2 (GND)

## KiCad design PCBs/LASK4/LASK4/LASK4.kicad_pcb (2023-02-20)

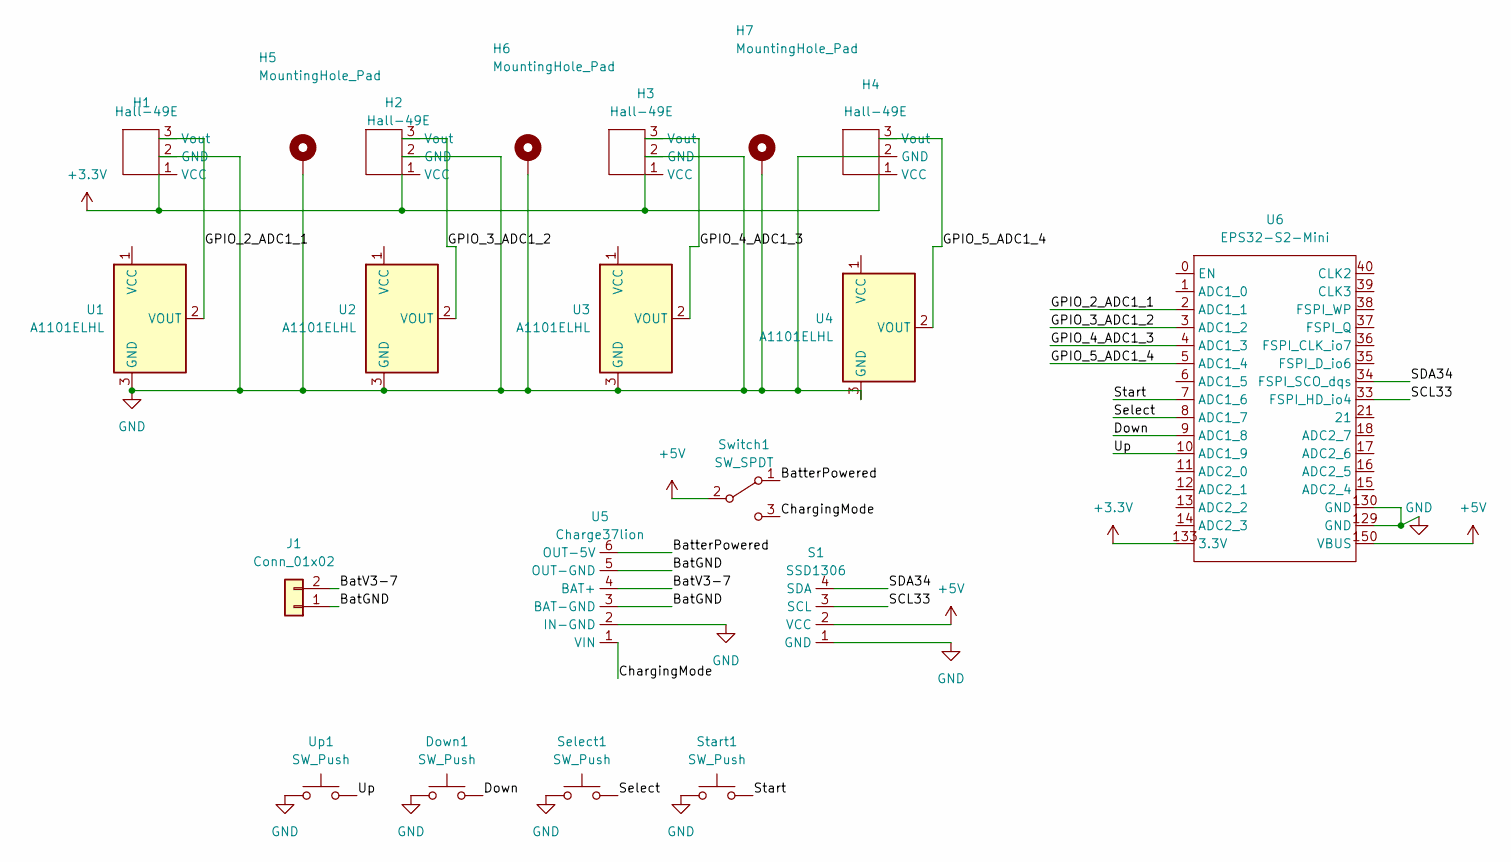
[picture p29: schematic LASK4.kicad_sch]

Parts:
Down1: SW_Push; SW_PUSH_6mm
H1, H2, H3, H4: Hall-49E; PinHeader_1x03_P2.00mm_Vertical
H5, H6, H7: MountingHole_Pad; MountingHole_2.2mm_M2_DIN965_Pad
J1: Conn_01x02; PinHeader_1x02_P2.54mm_Vertical
S1: SSD1306; PinHeader_1x04_P2.54mm_Vertical
Select1: SW_Push; SW_PUSH_6mm
Start1: SW_Push; SW_PUSH_6mm
Switch1: SW_SPDT; PinHeader_1x03_P2.54mm_Vertical
U1, U2, U3, U4: A1101ELHL; SOT-23W
U5: Charge37lion; PinHeader_1x06_P2.54mm_Vertical
U6: EPS32-S2-Mini; ESP32-S2-Mini
Up1: SW_Push; SW_PUSH_6mm

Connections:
+3.3V: H1.1 (VCC), H2.1 (VCC), H3.1 (VCC), H4.1 (VCC), U6.133 (3.3V)
+5V: S1.2 (VCC), Switch1.2 (B), U6.150 (VBUS)
/BatGND: J1.1, U5.3 (BAT-GND), U5.5 (OUT-GND)
/BatV3-7: J1.2, U5.4 (BAT+)
/BatterPowered: Switch1.1 (A), U5.6 (OUT-5V)
/ChargingMode: Switch1.3 (C), U5.1 (VIN)
/Down: Down1.2, U6.9 (ADC1_8)
/GPIO_2_ADC1_1: H1.3 (Vout), U1.2 (VOUT), U6.2 (ADC1_1)
/GPIO_3_ADC1_2: H2.3 (Vout), U2.2 (VOUT), U6.3 (ADC1_2)
/GPIO_4_ADC1_3: H3.3 (Vout), U3.2 (VOUT), U6.4 (ADC1_3)
/GPIO_5_ADC1_4: H4.3 (Vout), U4.2 (VOUT), U6.5 (ADC1_4)
/SCL33: S1.3 (SCL), U6.33 (FSPI_HD_io4)
/SDA34: S1.4 (SDA), U6.34 (FSPI_SCO_dqs)
/Select: Select1.2, U6.8 (ADC1_7)
/Start: Start1.2, U6.7 (ADC1_6)
/Up: U6.10 (ADC1_9), Up1.2
GND: Down1.1, H1.2 (GND), H2.2 (GND), H3.2 (GND), H4.2 (GND), H5.1, H6.1, H7.1, S1.1 (GND), Select1.1, Start1.1, U1.3 (GND), U2.3 (GND), U3.3 (GND), U4.3 (GND), U5.2 (IN-GND), U6.129 (GND), U6.130 (GND), Up1.1

Board: 2 copper layers, 20 parts (1 on the bottom side), 17 nets, no tracks yet.

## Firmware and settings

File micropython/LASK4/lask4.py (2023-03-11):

#OpenMuscle - OpenHand V1.0.0
# 4 Finger Target Value Acquirer

import machine
import time
import network
import socket
import ssd1306
import gc

# Globals
# defin ADCs and make loud
zero = [0,0,0,0]
hall = []
mins = [4156, 3961, 3617, 4157]

maxes = [5064, 5241, 5077, 5233]
ram = []
led = False
ledPIN = 15
sclPIN = 33
sdaPIN = 34
oledWIDTH = 128
oledHEIGHT =  32
startPIN = 7
selectPIN = 8
upPIN = 9
downPIN = 10
s,wlan = False,False

#Button variables
start = machine.Pin(startPIN,machine.Pin.IN,machine.Pin.PULL_UP)
select = machine.Pin(selectPIN,machine.Pin.IN,machine.Pin.PULL_UP)
up = machine.Pin(upPIN,machine.Pin.IN,machine.Pin.PULL_UP)
down = machine.Pin(downPIN,machine.Pin.IN,machine.Pin.PULL_UP)

#Startup Sequence
led = machine.Pin(15,machine.Pin.OUT)



def blink(x):
  for _ in range(x):
    led.value(1)
    time.sleep(.3)
    led.value(0)
    time.sleep(.2)

blink(7)

def initOLED(scl=machine.Pin(sclPIN),sda=machine.Pin(sdaPIN),led=led,w=oledWIDTH,h=oledHEIGHT):
  print('scl = ',scl)
  print('sda = ',sda)
  oled = False
  i2c = False
  try:
    i2c = machine.I2C(scl=scl,sda=sda)
  except:
    print('i2c failed check pins scl sda')
    try:
      print('i2c.scan() = ',i2c.scan())
    except:
      print('i2c.scan() failed')
  if i2c:
    try:
      oled = ssd1306.SSD1306_I2C(w,h,i2c)
      print("SSD1306 initialized[Y]")  
      print('oled = ',oled)
    except:
      print("failed to initialize onboard SSD1306")
  return oled

oled = initOLED()

def frint(text,oled=oled,ram=ram):
  if oled:
    if text:
      text = str(text)
      if len(text) <= 16:
        ram.append(text)
      else:
        ram.append(text[0:5]+'..'+text[len(text)-9:])
    oled.fill(0)
    n = 0
    for i in ram[-4:]:
      oled.text(i,0,n*8)
      n+=1
    if len(ram) > 9:
      ram = ram[-9:]
    gc.collect()
    oled.show()
    print('f:> ',ram[-1])
  else:
    print('f:< ',text)


def initNETWORK():
  #need optional backup UDP repl if can't connect
  #primary and secondary networks
  #if primary then try secondary dev wifi access point
  wlan = network.WLAN(network.STA_IF) 
  wlan.active(False)
  wlan.active(True)
  time.sleep(1)
  frint('connecting to wifi now')
  wlan.connect('OpenMuscle','3141592653')
  while not wlan.isconnected():
    pass
  print('assinging port and bind')
  port = 3145
  frint(f'network config:{wlan.ifconfig()}')
  frint('network connected[Y]')
  s = socket.socket(socket.AF_INET,socket.SOCK_DGRAM)
  return(s,wlan)
  
def read_all(hall=hall):
  reads = []
  for i,x in enumerate(hall):
    reads.append(x.read())
    print(i,x,reads[-1])
  return(reads)
    
    

def callibrate(hall=hall,start=start):
  global mins
  global maxes
  frint('plese RELEASE')
  frint('all depressors')
  time.sleep(2)
  mins = []
  maxes = []
  for i,x in enumerate(hall):
    maxes.append(x.read())
    print(i,x)
  frint('please PRESS')
  frint('all dep & strt')
  end = False
  while not end: 
    if start.value() == 0:
      end = True
      for i,x in enumerate(hall):
        mins.append(x.read())
        print(i,x)



def taskbar(hall=hall,oled=oled):
  oled.fill(0)
  oled.text('OM-LASK4 V1',0,0,1)
  x = 87
  y = 17
  global mins
  global maxes
  ammount = 5
  oled.fill_rect(0+x,0+y,40,14,1)
  oled.fill_rect(1+x,1+y,38,12,0)
  for i,z in enumerate(hall):
    div_top = (z.read()-mins[i])
    div_bottom = (maxes[i]-mins[i])
    if div_bottom == 0:
      div_bottom = 1
    ch = int((div_top/div_bottom)*12)
    r_x = ((i+1)*7)+x
    r_y = 13-(ch)+y
    oled.fill_rect(r_x,r_y,5,ch,1)
    oled.text(str(i+1),i*20,16,1)
    oled.text(str(ch*8),i*20,24,1)
  oled.show()
  
  

frint('OM-LASK4 Boot')




for i in range(2,6):
  temp = machine.ADC(machine.Pin(i))
  temp.atten(machine.ADC.ATTN_11DB)
  hall.append(temp)

cells = [hall[0],hall[1],hall[2],hall[3]]
read_all()

plen = 10
pi = 0
calib = [0,0,0,0]
blink(2)

def drawMenu():
  frint('OM-LASK4 Menu')


def fastRead(cells=cells):
  global s
  packet = {}
  data = []
  for i in range(len(cells)):
      data.append(cells[i].read()-calib[i])
  packet['id'] = 'OM-LASK4'
  packet['ticks'] = time.ticks_ms()
  packet['time'] = time.localtime()
  #Append the cycle with : deliminer delimeter
  packet['data'] = data
  raw_data = str(packet).encode('utf-8')
  try:
    #UDP recepient address
    s.sendto(raw_data,('192.168.1.32',3145))
    status = str(packet)
  except:
    status = 'failed'
  #return(status)


def mainMenu():
  global start
  global select
  global up
  global down
  global oled
  global s
  global wlan
  menu = [['[0] Wifi Connect',0,0],['[1] Callibrate',1,1],['[2] UDP Send',2,1],['[3] Exit',3,1]]
  end = False
  while not end:
    oled.fill(0)
    for i,x in enumerate(menu):
      oled.fill_rect(0,i*8,128,8,abs(x[2]-1))
      oled.text(x[0],0,i*8,x[2])
    oled.show()
    if start.value() == 0 and menu[0][2] == 0:
      frint('init network')
      s,wlan = initNETWORK()
      cells = [hall[3],hall[2],hall[1],hall[0]]
      try:
        import ntptime
        ntptime.settime()
        time.localtime()
        print(time.localtime())
      except:
        frint('NTP Time [f]')
        frint('failed to set NTP time')
      return
    if start.value() == 0 and menu[3][2] == 0:
      return
    if start.value() == 0 and menu[2][2] == 0:
      while True:
        fastRead()
        if select.value() == 0:
          return
    if start.value() == 0 and menu[1][2] == 0:
        callibrate()
        return
    if up.value() == 0 or down.value() == 0:
      for i,x in enumerate(menu):
        if x[2] == 0:
          if up.value() == 0:
            menu[i][2] = 1
            menu[i-len(menu)+1][2] = 0
            time.sleep(.3)
          if down.value() == 0:
            menu[i][2] = 1
            menu[i-1][2] = 0
            time.sleep(.3)
            
    




def mainloup(pi=pi,plen=plen,led=led,cells=cells,start=start,select=select,up=up,down=down):
  count = 0
  exit_bool = False
  button_thresh = 0
  while not exit_bool:
    if up.value() == 0 or down.value() == 0:
      mainMenu()
    if select.value() == 0:
      button_thresh += 1
    else:
      button_thresh += -1
    if button_thresh > 20:
      exit_bool = True
    elif button_thresh < 0:
      button_thresh = 0
    if pi == 0:
      frint('first run')
      #callibrate()
    if pi >= 10:
      taskbar()
      count += 1
      pi = 1
    else:
      pi += 1
    

mainloup()
print('this is after mainloup()')

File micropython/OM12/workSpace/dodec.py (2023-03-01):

#udodec.py


import neopixel
import machine
import time
import gc
import random
print('hello world!')

np = neopixel.NeoPixel(machine.Pin(39),300)
for i in range(300):
  np[i] = (10,10,10)
np.write()

for i in range(300):
  np[i] = (0,0,0)
np.write()

verts= [[-1,2,3],
[-3,4,5],
[-5,6,7],
[-7,8,9],
[-9,10,1],
[-4,-17,18],
[-14,15,-2],
[-10,11,12],
[-8,-23,24],
[-6,-20,21],
[20,-18,19],
[17,-15,16],
[14,-12,13],
[-11,-24,25],
[23,-21,22],
[-19,-29,30],
[29,-16,-28],
[28,-13,-27],
[27,-25,26],
[-26,-22,-30]] 

faces = [
[1,3,5,7,-9],
[9,8,24,-11,-10],
[-8,-7,6,21,23],
[6,-20,-18,4,5],
[-4,-3,2,15,17],
[-2,-1,10,12,14],
[-12,11,25,27,-13],
[13,28,-16,-15,-14],
[16,29,-19,-18,-17],
[19,30,-22,-21,-20],
[22,-26,-25,-24,-23],
[26,-30,-29,-28,-27]]

sequence = 'RLLRLLLLBLL'
tracers = False
die_rate = 20
pixel = []

def run_once(np=np):
  for i in range(300):
    np[i] = (255,127,0)
    np.write()
    time.sleep(.01)
    np.buf = bytearray(900)
    np.write()
  return
  
  
def count_edges(np=np):
  for i in range(30):
    for a in range(10):
      np[(i*10)+a] = (127,127,255)
    np.write()
    time.sleep(1)
    print(f'group:{i*10}-{((i+1)*10)-1}')
    input()
    for a in range(10):
      np[(i*10)+a] = (27,0,0)
    np.write()
    
    
    
def convert_directions(text):
  numeric = []
  for i in text:
    if i == 'R':
      numeric.append(-2)
    if i == 'L':
      numeric.append(-1)
    if i == 'B':
      numeric.append(-3)
  return numeric
  
def change_color(cp,rgb):
  global edges
  hits = edges[abs(cp)][1]
  new_rgb = [0,0,0]

  new_rgb[hits%3] += 11
  r = rgb[0] + new_rgb[0]
  g = rgb[1] + new_rgb[1]
  b = rgb[2] + new_rgb[2]
  edges[abs(cp)][1] += 1
  return (r,g,b)
  
  
 
def dim(die_rate=die_rate,np=np):
  for i in range(len(np)):
    if np[i][0] + np[i][1] + np[i][2] > 0:
      r = np[i][0] - die_rate
      g = np[i][1] - die_rate
      b = np[i][2] - die_rate
      if r < 0:
        r = 0
      if g < 0:
        g = 0
      if b < 0:
        b = 0
      np[i] = (r,g,b)

    
def move(verts=verts,np=np):
  global tracers
  global pixel
  newp = None
  gc.collect()
  newp = []
  np.buf = bytearray(900)
  for p in pixel:
    edge = p[0]
    pix = p[1]
    l = p[2]
    speed = p[3]
    pattern = p[4]
    adjustment = p[5]
    ttl = p[6]
    pat = convert_directions(pattern)
    found = False
    for num in range(speed):
        if pix + 1 > 9:
          ttl -= 1
          for i,x in enumerate(verts):
            if -edge in x and not found:
              #print(f'edge:{edge}',f'Vertici:{x}',f'pattern:{p}')
              indie = x.index(-edge)
              edge = x[indie+pat[0]]
              #print(f'new edge:{edge} indie:{indie} pat[0]:{pat[0]}')
              found = True
          pattern = pattern[1:] + pattern[0]
          pix = pix + 1 - 10
        else:
          pix = pix + 1
        if edge > 0:
          np[(edge*10)-10+pix] = adjustment
        elif edge < 0:
          np[(-edge*10)-10+(9-pix)] = adjustment
    if ttl != 0:
      newp.append([edge,pix,l,speed,pattern,adjustment,ttl])
  np.write()
  pixel = newp


print('right before!')
#iterate_route('RLLRLLLLBLL',50)

pixel.append([i,0,1,3,'RLLRLLLLBLL',(r,g,b),-1])

for i in range(1000):
  move()

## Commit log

2022-09-03 MainCell0Upload
    Updated Project with main comp file structure
    [CELL0-1v3-fix.dsn, CELL0.kicad_sch, Cello-Compute.kicad_sch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]
2022-09-07 Cello-Compute-Gerber
    Gerber files for the Cello Compute module
2022-09-07 CELL0 Gerber Files Added
2022-10-10 created open muscle wireless access point
2022-10-19 PCB update
    Need to organize but I'm behind on my documentation. Here are the current PCBs gerber files and others.
    [OM6.kicad_pcb, OM6.kicad_sch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]
2022-10-19 Going from ESP32-C3 wifi to external
2022-10-19 Delete ESP32-S2-OM-Boot.py
    Remove older boot file for OpenMuscle band
2022-10-19 STL file upload
    Need a lot better naming convention :
    [00 Better Cap.stl, 00 Better Tubes.stl, 00 CModule 2.stl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]
2022-11-05 BackupUploads
    UPloadbakcup py files for esp32-s2 and ssd1306
2022-11-22 MAJOR update
    a
    [csv_file.csv, myfile.csv, training_file0.csv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]
2023-01-12 minor update overhaul
    minor update overhaul
    # Pinout Uploads
    # STL file adjustments
    # Training Data testing
    # Lask System Upload
    ## Major revisions coming back to back as we enter in a new phase in development.
    [00 Better Cap.stl, 00 Better Tubes.stl, 00 CModule 2.stl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]
2023-01-29 Major Update
    [Forearm_Measurements.xlsx, LASK4.kicad_pcb, LASK4.kicad_sch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]
2023-01-30 LASK4 Update
    Updated LASK4 PCB and pertaining documents.
    [LASK4-B_Cu.gbr, LASK4-B_Mask.gbr, LASK4-B_Paste.gbr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]
2023-02-18 LASK4
    Updates
    [OM6.kicad_sch]
2023-03-01 ML Learning & Virt Env
    [housing.csv]
2023-03-16 Major Update OM12
    Major Update To isolate only the current working version from all the others.
    [00 Better Cap.stl, 00 Better Tubes.stl, 00 CModule 2.stl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]
2023-03-16 OM12 V7 Update
    OM12 7 is the latest and yet to be built prototype
    [OpenMuscle7.kicad_pcb, OpenMuscle7.kicad_sch]
2023-03-16 OM12 Working Prototype Proof of Concept
    OM12 Major update includes all files for the working proof-of-concept of OpenMuscle12 also referred to as OM5.3.0
    UDP Server for collecting data from LASK4 and OM12
    Basic Packet Matching txt2csv.py python function
    Overall Basic Functionality of Hardware and Software
    Machine Learning Not Yet Started
    [OpenMuscle7.kicad_pcb, OpenMuscle7.kicad_sch, csv_file.csv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]
2023-03-16 Decent Captured Data
    [datasetTWO.csv]
2023-03-17 Image-update
    Update Description and Images for OM12 5.3.0
    [datasetTWO.csv]
2023-03-26 OM Machine Learning Data
    Backup of the Raw data to train the Random Forest Regressor shown on the latest update on openmuscle.org 3-26-2023
    # Wanted to include both the january and march dataset.
    [datasetTWO.csv, datasetTWOish.xlsx, predictions_vs_actuals.csv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]
2023-03-28 Machine Learning Update
    Includes link to the shared model and all the code to predict live sensor output and create predicted output CSV.
2023-03-29 Live Training with only 5 min of data files :D
    Uploaded a video where I trained the data and had it predict in real-time. These are the adjustments made for that video.
    [ClevisFeet.stl, March2823training_file9.csv]
2023-04-01 Demo Update
    [predictions_vs_actuals.csv, predictions_vs_actuals.xlsx, training_file9_USED TO TRAIN MODEL.csv]
2023-04-01 Major Org Update
    [ClevisFeet.stl, OM12-BeltHolder.stl, OM12-FoamHolder.stl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]
2023-04-02 Demo Initial Tests
    [capture_9_demo_train.csv, p_vs_a_jan23.csv, training_file51.csv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]
2023-04-02 Included Time Domain or Slope
    [capture_11.csv]
2023-04-02 Demo 4-2-23
    [capture_010.csv, capture_11.csv, capture_9_demo_train.csv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]
2023-04-16 January 23 Data Files for Training Update
    https://openmuscle.org/finger-movement-recognition-using-radial-pressure-sensors-on-the-forearm-and-machine-learning-techniques/
    [predictions_vs_actuals Short Segment.csv, predictions_vs_actuals Short Segment_shorter.csv, predictions_vs_actuals.csv]
2023-04-16 Other Datasets
    These datasets show a great accuracy result from Random Forest Regressor. January23 was the most accurate and used OM12 5.3.0 hardware and PCB.
    [capture_010.csv, capture_9_demo_train.csv, training_file51.csv]
2023-04-16 Demo Predictions for Jan23 Dataset
    Includes training file to look at the largest dataset: January23
    [Predictions With OM and LASK.csv, Predictions With OM and LASK2.csv, predictions_vs_actuals_Evaluate.csv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]
2023-04-19 Demo Organize
    Organized Demo Files
    [Predictions With OM and LASK2.csv, avp-4-2-23.csv, predictions_vs_actuals Short Segment.csv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]
2023-04-19 om12 clevis stl
    [LASK4-BASEv2.stl, LASK4-BatteryHolder.stl, LASK4-MagnetDepressors.stl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]
2024-10-24 LASK5 DevKit
    [LASK5-B_Cu.gbr, LASK5-B_Mask.gbr, LASK5-B_Paste.gbr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]
2024-10-24 Added uLabel depressor
    See Ultimate Robotics uMyo and uLabel for more info.
    [uLabel-Depressor-v31.stl]
